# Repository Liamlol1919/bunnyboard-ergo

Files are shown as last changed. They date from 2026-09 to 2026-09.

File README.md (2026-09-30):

# bunnyboard
this is a custom stenography keyboard i built with [hackclub's onboard grant](https://onboard.hackclub.com)!

## ergo variant (working copy)
This tree contains a transformed variant of the original bunnyboard: the same
electrical design (pads, nets, matrix, diodes, Pico pinout are bit-identical),
only the (x, y, rot) values of the 28 switches, 28 diodes and the Pico are
changed. Generated by `tools/ergo_transform.py`, routed by `tools/route.sh`.

### pitch: 19 mm grid, not measured fingertip distance
Two candidates were compared (`tools/vergleich_pitch.py`):

| | Pinky-Index | Ring-Middle cap gap |
|---|---|---|
| V1 fingertip (Wacom dx) | 56.0 mm | **0.5 mm** |
| V2 19 mm switch grid | 57.0 mm | **4.0 mm** |

V1 is rejected: a 0.5 mm gap between the Ring and Middle caps means a
mis-hit presses two keys at once. The measured fingertip spacing is narrower
than the switch grid because the hand rests spread out; the grid has to
follow the switch pitch (Choc = 19 mm), not the fingertips. Stagger (dy) is
taken from the measurement - that is the actual ergonomic effect.

### middle gap: 120 mm
The two middle fingers sit 120 mm apart (measured: 84-92 mm). The extra width
pays for the Pico: it is 23.1 mm wide and sits between the asterisk columns,
which additionally need 2 x 9.125 mm for their diode offsets plus clearance
-> 42.1 mm between the asterisk caps. At 96 mm the asterisks were only 28 mm
apart and the Pico overlapped S6/S17.

### thumb rotation: 3 degrees
The 3 thumb keys per hand are rotated so they face the thumb instead of
standing axis-parallel. Left hand +3, right hand -3.
NOTE: the Choc footprint is NOT mirror-symmetric - all six thumb switches
have the same pad axis (22.78 deg) in the source board. The sign therefore
cannot be derived from "mirror the left hand"; it is set per hand and must
be verified visually on the render. The angle is limited by the caps, not by taste:
a Choc-1u cap is 17.5 x 16.5 mm (the 15 mm used in the first calculation was
too optimistic), and rotating a cap by a widens its bounding box to
17.5*(cos a + sin a). S23 and S24 are 19.36 mm apart:

| angle | cap bbox | gap S23-S24 |
|---|---|---|
| 0 | 17.50 mm | +1.86 mm |
| **3 (chosen)** | 18.39 mm | **+0.97 mm** |
| 6 | 19.23 mm | +0.13 mm |
| 12 | 20.76 mm | -1.40 mm overlap |

DRC does not catch cap collisions - it only checks copper. At 12 degrees the
two caps physically touch, which only shows up during assembly.

### chamfer: outer corners only
The T-outline transition from the bank to the tongue is a concave corner.
A chamfer there cuts away material the corner needs. Fase is applied only to
the convex corners: the 4 bank corners and the 2 tongue ends.

### outline
`Edge.Cuts` is rebuilt as a T shape from the actual key extents, not from the
raw bounding box of the source board. Margin is 4 mm from the keycap edge
(previously 12.5 mm as in bunnys original): a board that lies flat does not
need more, and JLCPCB only requires 0.2 mm copper-to-edge - the smallest
actual copper-to-edge distance here is 1.62 mm.

The copper logo (`G***`) was removed: it is decoration and cost board area.

| | before | after |
|---|---|---|
| Board | 253.6 x 114.2 mm | **236.6 x 97.2 mm** |
| Margin (cap edge to board edge) | 10.5-12.5 mm | 4.0 mm |
| Copper to edge (min) | - | 1.62 mm |

## specs and other stuff
- powered by a Raspberry Pi Pico
- runs QMK firmware
- uses Kailh choc v1 switches

## keyboard layout
the keyboard layout is almost identical to "The Uni" stenokeyboard, except for the top-left key (which is a "#" instead of an "S").
```
.------------------------------------------------.
| # | T | P | H | * |    | * | F | P | L | T | D |
| S | K | W | R | * |    | * | R | B | G | S | Z |
'-------| # | A | O |    | E | U | # |-----------'
        '----------------------------'
```
## how to get this keyboard
1. get the pcb and solder the components
   - PCB gerber located at "/keyboard/production/gerber.zip
   - components needed:
     - 28 kailh v1 choc switches + keycaps (i got mine for $32 USD at chosfox!)
     - raspberry pi pico + header pins
     - 28 1N4148 Diodes (you can choose to have them soldered on if you're using JLCPCB)
2. install the QMK firmware (read [here](https://docs.qmk.fm/newbs_flashing) for more info)
3. install/setup plover (see a tutorial [here](https://docs.stenokeyboards.com/guides/))
   - select "Gemini PR" as your keyboard
   - set output to "Enabled"
4. profit

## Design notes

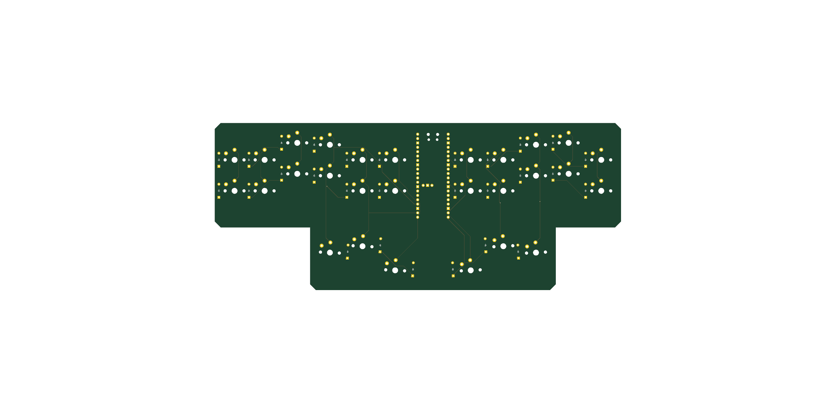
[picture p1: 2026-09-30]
docs/board_bottom.png

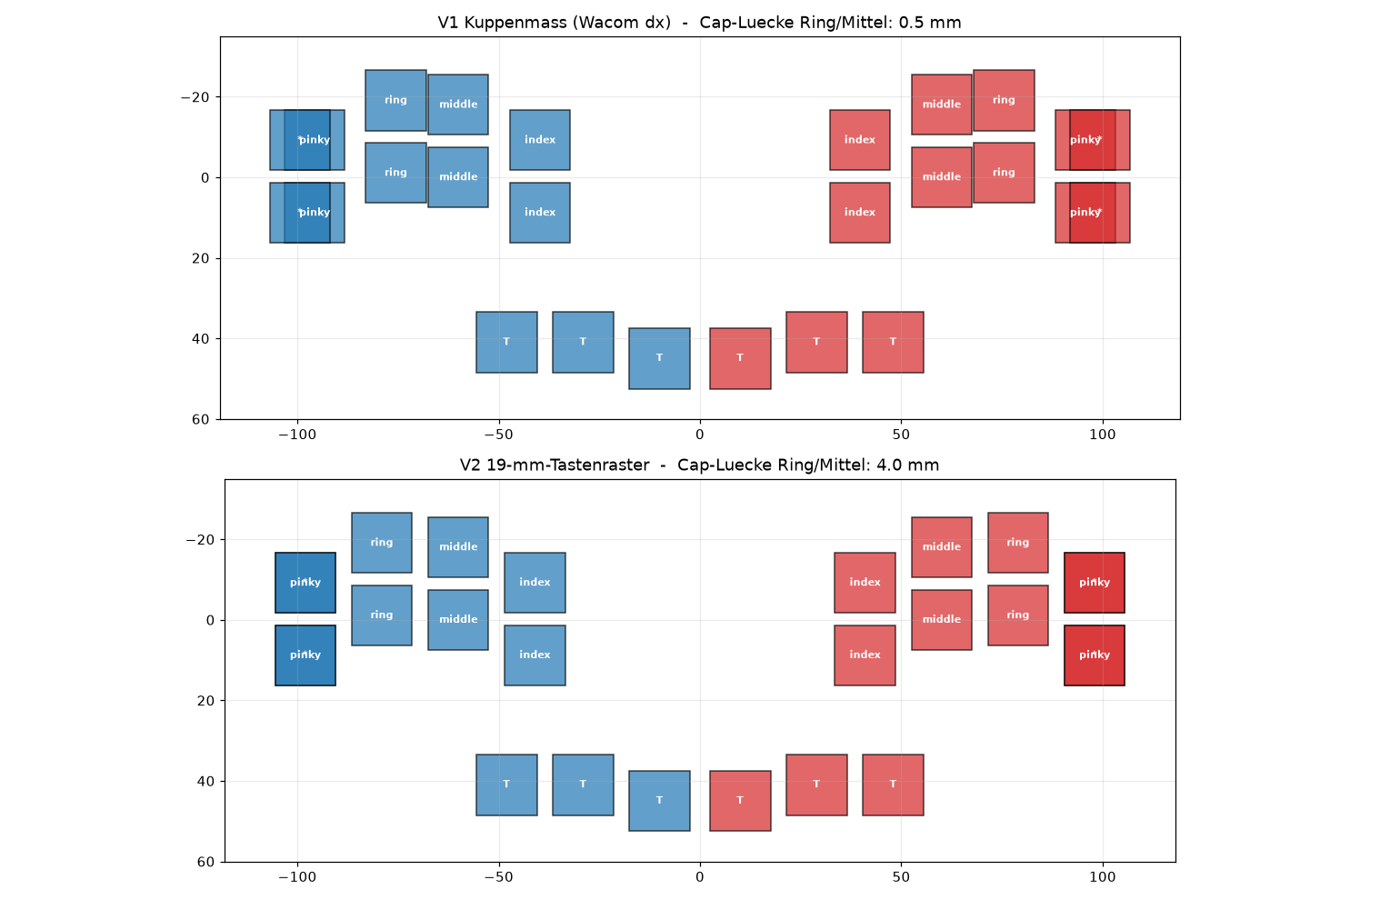
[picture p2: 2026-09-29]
vergleich_pitch.png

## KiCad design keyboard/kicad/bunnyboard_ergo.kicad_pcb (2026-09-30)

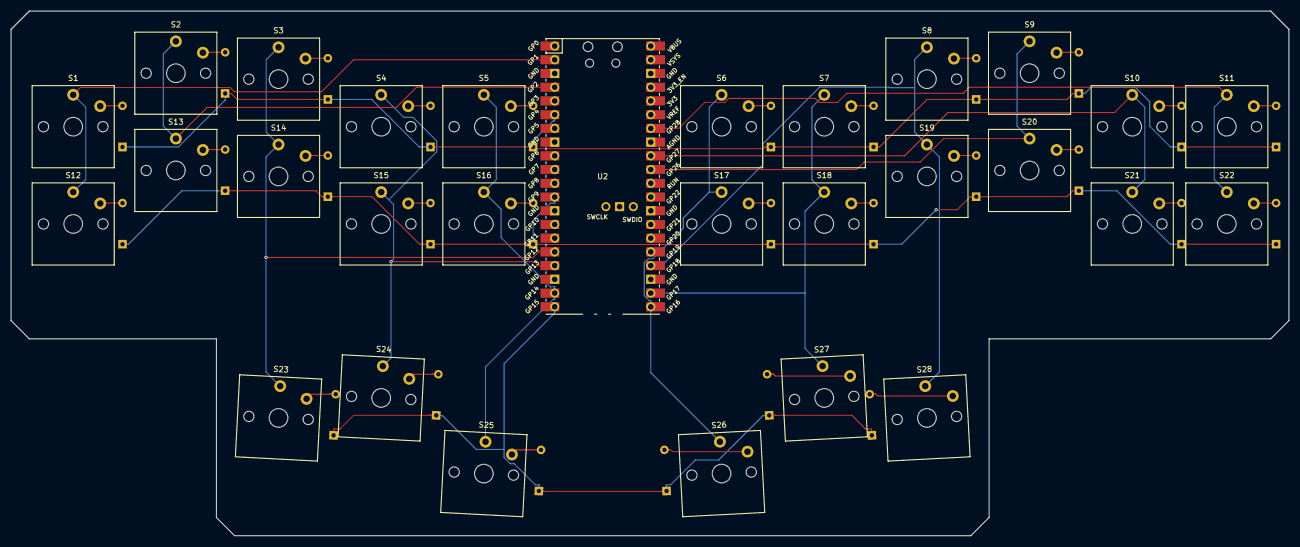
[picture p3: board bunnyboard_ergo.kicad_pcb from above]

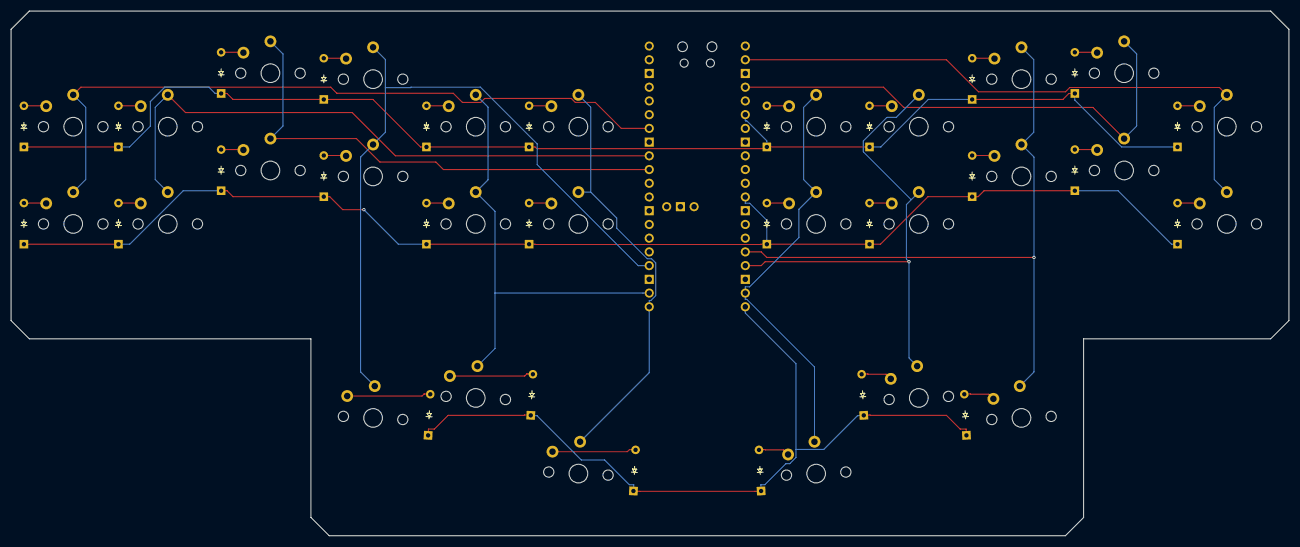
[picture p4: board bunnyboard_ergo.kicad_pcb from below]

Board: 2 copper layers, 236.5 x 97.1 mm, 57 parts (28 on the bottom side), 42 nets.

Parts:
D1, D2, D3, D4, D5, D6, D7, D8, D9, D10, D11, D12, D13, D14, D15, D16, D17, D18, D19, D20, D21, D22, D23, D24, D25, D26, D27, D28: D; Diode_DO-35
S1, S2, S3, S4, S5, S6, S7, S8, S9, S10, S11, S12, S13, S14, S15, S16, S17, S18, S19, S20, S21, S22, S23, S24, S25, S26, S27, S28: Keyswitch; Choc_V1_1.00u
U2: Pico; RPi_PicoW_SMD_TH

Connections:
Column 0: S1.1, S12.1, U2.2 (GPIO1)
Column 1: S2.1, S13.1, U2.4 (GPIO2)
Column 2: S3.1, S14.1, S23.1, U2.16 (GPIO12)
Column 3: S4.1, S15.1, S24.1, U2.17 (GPIO13)
Column 4: S5.1, S16.1, S25.1, U2.19 (GPIO14)
Column 5: S6.1, S17.1, S26.1, U2.21 (GPIO16)
Column 6: S7.1, S18.1, S27.1, U2.22 (GPIO17)
Column 7: S8.1, S19.1, S28.1, U2.24 (GPIO18)
Column 8: S9.1, S20.1, U2.31 (GPIO26_ADC0)
Column 9: S10.1, S21.1, U2.32 (GPIO27_ADC1)
Column 10: S11.1, S22.1, U2.34 (GPIO28_ADC2)
unnamed: D1.2 (A), S1.2
unnamed: D2.2 (A), S2.2
unnamed: D3.2 (A), S3.2
unnamed: D4.2 (A), S4.2
unnamed: D5.2 (A), S5.2
unnamed: D6.2 (A), S6.2
unnamed: D7.2 (A), S7.2
unnamed: D8.2 (A), S8.2
unnamed: D9.2 (A), S9.2
unnamed: D10.2 (A), S10.2
unnamed: D11.2 (A), S11.2
unnamed: D12.2 (A), S12.2
unnamed: D13.2 (A), S13.2
unnamed: D14.2 (A), S14.2
unnamed: D15.2 (A), S15.2
unnamed: D16.2 (A), S16.2
unnamed: D17.2 (A), S17.2
unnamed: D18.2 (A), S18.2
unnamed: D19.2 (A), S19.2
unnamed: D20.2 (A), S20.2
unnamed: D21.2 (A), S21.2
unnamed: D22.2 (A), S22.2
unnamed: D23.2 (A), S23.2
unnamed: D24.2 (A), S24.2
unnamed: D25.2 (A), S25.2
unnamed: D26.2 (A), S26.2
unnamed: D27.2 (A), S27.2
unnamed: D28.2 (A), S28.2
Row 0: D1.1 (K), D2.1 (K), D3.1 (K), D4.1 (K), D5.1 (K), D6.1 (K), D7.1 (K), D8.1 (K), D9.1 (K), D10.1 (K), D11.1 (K), U2.6 (GPIO4)
Row 1: D12.1 (K), D13.1 (K), D14.1 (K), D15.1 (K), D16.1 (K), D17.1 (K), D18.1 (K), D19.1 (K), D20.1 (K), D21.1 (K), D22.1 (K), U2.12 (GPIO9)
Row 2: D23.1 (K), D24.1 (K), D25.1 (K), D26.1 (K), D27.1 (K), D28.1 (K), U2.20 (GPIO15)

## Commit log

2026-09-29 ergo: T-Outline an Tasten, Pico in Mittelluecke, Routing 0 DRC
    - Edge.Cuts aus Tastenausdehnung neu gebaut (253.6 x 103.9 statt 234x171
    mit 65% Leerflaeche im Sueden)
    - GAP 96 -> 120: Pico (23.1 breit) braucht 2x9.125 Dioden-Offset + Luft
    zwischen den Asterisk-Kappen
    - Pico-Zentrum symmetrisch: rechts mid_r+DX_INDEX-19 (vorher fehlte -19,
    Pico lag auf S6/S17)
    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
    [bunnyboard_ergo.kicad_pcb]
2026-09-29 ergo: Pitch V2 dokumentiert, Logo mitverschoben, neu geroutet
    - README: Abschnitt 'ergo variant' mit Pitch-Entscheidung (V1 Kuppenmass
    verwworfen: 0.5 mm Cap-Luecke Ring/Mittel; V2 19-mm-Raster: 4.0 mm),
    GAP-120-Begruendung und Outline-Herkunft
    - vergleich_pitch.py auf GAP 120 nachgezogen (war 96)
    - Kupfer-Logo G*** mitverschoben: lag nach dem Transform ausserhalb von
    Edge.Cuts (Quelle 140.69/119.17 -> Ziel frei ueber der Bank, 104/-30)
    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
    [bunnyboard_ergo.kicad_pcb]
2026-09-29 ergo: Daumen-Cluster korrigiert (S23/S25 vertauscht), Produktionsdaten, Viewer
    Fehler gefunden beim Vergleich Quell- vs Zielboard:
    - Daumen-y war S23/S28=41.0 und S25/S26=44.7 - vertauscht. STAGGER.md:
    Taste1 (A/E, Ruhepunkt) +45, Taste2 (O/U, 19 innen) +41, Extra X1/X2 +55.
    Jetzt S23/S28=44.7, S24/S27=41.0, S25/S26=55.0.
    - keyboard/production/gerber.zip war das ORIGINAL vom 11.03.2024, nicht das
    Ergo-Board. Neu: keyboard/production/gerber_ergo.zip (26 Dateien) mit
    frischen Gerbern, Drill und positions.csv.
    docs/ergebnis.html: selbsttragender Viewer (Bilder inline + massstaeblicher
    SVG-Routingplan + Verifikationstabelle).
    Verifikation: 252 Tracks, 0 DRC, 0 unconnected, min Daumen-K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
    [bunnyboard_ergo-B_Courtyard.gbr, bunnyboard_ergo-B_Cu.gbl, bunnyboard_ergo-B_Fab.gbr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]
2026-09-29 ergo: Board kompakter - Logo raus, Rand 10.5 -> 4.0 mm
    - Kupfer-Logo G*** entfernt (Dekoration, kostete Flaeche). Wichtig: Remove()
    vor dem Track-Loeschen, sonst toter SWIG-Handle (Segfault in der
    Footprint-Iteration).
    - Rand vom Kappenrand zur Boardkante 10.5-12.5 -> 4.0 mm rundum. Neuer
    Umriss beruecksichtigt zusaetzlich den Pico, der 7 mm ueber die Bank ragt
    (haette sonst ausserhalb von Edge.Cuts gelegen).
    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
    [bunnyboard_ergo-B_Courtyard.gbr, bunnyboard_ergo-B_Cu.gbl, bunnyboard_ergo-B_Fab.gbr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]
2026-09-30 ergo: Daumen 3 Grad gedreht, Innen-Fase entfernt
    Umriss:
    - Chamfer nur noch an konvexen Ecken (4 Bank-Ecken, 2 Zungen-Enden). Der
    Bank->Zunge-Uebergang ist konkav - eine Fase schnitt dort Material weg,
    das die Ecke traegt. 16 -> 14 Punkte.
    Daumen:
    - Die 6 Daumentasten sind um 3 Grad zum Daumen gedreht (links negativ,
    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
    [bunnyboard_ergo-B_Courtyard.gbr, bunnyboard_ergo-B_Cu.gbl, bunnyboard_ergo-B_Fab.gbr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]
2026-09-30 ergo: Daumen rechts korrigiert (links +3, rechts -3), Dioden im Cluster entzerrt
    - Drehrichtung rechts umgekehrt: vorher beide -3, jetzt links +3 / rechts -3.
    Das Choc-Footprint ist nicht spiegelsymmetrisch (alle 6 Daumentasten haben
    im Quellboard dieselbe Pad-Achse 22.78 Grad), die Spiegelung ergibt sich
    daher nicht aus dem Vorzeichen allein.
    - Dioden-Offsets im Daumencluster explizit je Taste (THUMB_DIODE_OX).
    Vorher kollidierten D27 (+10 -> x=51.2) und D28 (-8 -> x=52.2) mit 1 mm
    Abstand (courtyards_overlap). Jetzt zeigen alle zur Cluster-Mitte:
    S23/S28 8.0, S24/S25/S26/S27 10.0, jeweils mit Seitenvorzeichen.
    - Verifikation: 283 Tracks, 0 DRC, 0 unconnected, 0 ausserhalb Edge.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
    [bunnyboard_ergo-B_Courtyard.gbr, bunnyboard_ergo-B_Cu.gbl, bunnyboard_ergo-B_Fab.gbr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]
2026-09-30 ergo: Viewer-Bug behoben (SVG ohne Groesse), Daumen-Vorzeichen getauscht
    Viewer:
    - Die Plaene hatten viewBox-Werte in Pixeln, aber width/height fehlten, und
    der Zoom erbte die volle Boardhoehe (1626x2301 statt ~600x600). Deshalb war
    nichts zu sehen. Jetzt explizite width/height + eigener Crop fuer den Zoom.
    - docs/ergebnis.html zeigt beide Vorzeichen-Varianten nebeneinander:
    A links +3 / rechts -3, B links -3 / rechts +3.
    - Vorzeichen getauscht: links jetzt -3, rechts +3.
    - Pipeline neu gelaufen: 290 Tracks, 0 DRC, 0 unconnected.
    Umschalten ist eine Zeile in tools/ergo_transform.py (THUMB_ROT-Zeichen
    in den sechs out[...]-Zeilen bei target_positions()).
    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
    [bunnyboard_ergo-B_Courtyard.gbr, bunnyboard_ergo-B_Cu.gbl, bunnyboard_ergo-B_Fab.gbr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]
2026-09-30 ergo: Daumen-Vorzeichen auf die am PCB bestaetigte Variante A zurueck
    - Vorzeichen wieder links +3 / rechts -3. Der Tausch auf B in 2685737 war
    falsch (Nutzer hat A am PCB bestaetigt).
    - Nur S23-S28 werden gedreht; S1-S22 und der Pico bleiben bei rot = 0.
    - Veralteten Kommentar korrigiert: der Winkel kommt nicht aus der gemessenen
    Daumenachse (125-134 Grad), sondern ist durch die Kappenbreite begrenzt.
    - Viewer: beide Daumen-Cluster einzeln im Zoom statt einer Vorzeichen-
    Gegenueberstellung, da die Richtung jetzt feststeht.
    - 283 Tracks, 0 DRC, 0 unconnected.
    [bunnyboard_ergo-B_Courtyard.gbr, bunnyboard_ergo-B_Cu.gbl, bunnyboard_ergo-B_Fab.gbr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]
2026-09-30 ergo: Daumen links/rechts entgegengesetzt gedreht, Plan in Render-Orientierung
    - Links -3 Grad, rechts +3 Grad. Vorher drehten beide Seiten gleichsinnig
    (Render-Achse beide -19.78 bzw. beide -25.78), die Kappen kippten also
    nicht gespiegelt zueinander.
    - Nachweis ueber die Pad-Achse im Render-Koordinatensystem (y nach oben):
    links -25.78 Grad, rechts -19.78 Grad -> gespiegelt.
    - Plan (docs/ergebnis.html) wird jetzt in derselben Orientierung wie der
    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
    [bunnyboard_ergo-B_Courtyard.gbr, bunnyboard_ergo-B_Cu.gbl, bunnyboard_ergo-B_Fab.gbr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]
2026-09-30 docs: Plan-Orientierung korrigiert, Daumen-Zoom entfernt
    - Der Gesamtplan war vertikal gespiegelt: die Zunge stand oben statt unten.
    Ursache war ein falsch zusammengesetztes scale(1,-1)+translate. Jetzt wird
    y direkt als (Y1-y)*S abgebildet, ohne Transform: Bank oben (breit),
    Zunge unten (schmal) wie im 3D-Render.
    - Daumen-Zoom entfernt, es bleibt nur der Gesamtplan.
    - Das PCB selbst ist unveraendert (Render byte-identisch).
2026-09-30 docs: Plan y-Achse korrigiert - KiCad bildet +y nach unten ab
    - Falsche Annahme korrigiert: der 3D-Render bildet +y nach UNTEN ab (wie die
    Datei), nicht nach oben. Meine letzte Aenderung (y gespiegelt, Winkel
    negiert) hat den Plan deshalb umgedreht: Zunge stand oben.
    - Jetzt wieder py(y)=(y-Y0)*S und Winkel unveraendert.
    - Verifiziert am gelieferten HTML: Zunge y 306..474 (unten), Daumen plan-y
    421, Bank oben - deckt sich mit board_top.png (Bank oben 1158 px breit,
    Zunge unten 700 px).
    - PCB/Render unveraendert.
2026-09-30 ergo: Daumenwinkel auf 6 Grad (nach innen)
    - THUMB_ROT 3 -> 6. Richtung unveraendert (links -6, rechts +6).
    - Nur S23-S28 gedreht; S1-S22 und Pico bleiben bei 0. PCB-Geometrie
    (Umriss, Pico, Finger) unangetastet.
    - Kappenluecke S23-S24 sinkt von 0.94 auf 0.13 mm (Kappen-BBox 19.23 mm
    bei 19.36 mm Mittenabstand). Ab 8 Grad ueberlappen die Kappen.
    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
    [bunnyboard_ergo-B_Courtyard.gbr, bunnyboard_ergo-B_Cu.gbl, bunnyboard_ergo-B_Fab.gbr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]
2026-09-30 ergo: Daumen 9 Grad in V-Form (links +9, rechts -9)
    - Richtung gedreht: links +THUMB_ROT, rechts -THUMB_ROT. Die Kappen kippen
    damit zur Mitte nach oben, es entsteht ein V zwischen den Daumen.
    Vorzeichen ueber die Oberkanten-Normale im SVG-Koordinatensystem
    hergeleitet: n = (sin a, -cos a); links muss nach rechts kippen (a>0),
    rechts nach links (a<0). Gegenprobe Pad-Achse: links 13.78, rechts 31.78.
    - Winkel 9 Grad (nicht 6): 3 Grad + 6 Grad weiter nach innen.
    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
    [bunnyboard_ergo-B_Courtyard.gbr, bunnyboard_ergo-B_Cu.gbl, bunnyboard_ergo-B_Fab.gbr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]
2026-09-30 ergo: Daumenwinkel zurueck auf 3 Grad, V-Form beibehalten
    - THUMB_ROT 9 -> 3. Richtung unveraendert: links +3 (Kappe kippt nach
    rechtsoben), rechts -3 (nach linksoben) -> V zwischen den Daumen.
    - Dioden-Offsets bleiben bei +-10.0 (zur Cluster-Mitte).
    - Nur S23-S28 gedreht; S1-S22 und Pico bei 0. Umriss/Pico unveraendert,
    Board 236.6 x 97.2 mm.
    - 282 Tracks, 0 DRC, 0 unconnected.
    [bunnyboard_ergo-B_Courtyard.gbr, bunnyboard_ergo-B_Cu.gbl, bunnyboard_ergo-B_Fab.gbr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]
2026-09-30 ergo: Daumenrichtung umgedreht, 3 Grad (links -3, rechts +3)
    - Vorzeichen getauscht: links -THUMB_ROT, rechts +THUMB_ROT. Die
    Kappen-Oberkante kippt jetzt von der Mitte nach aussen.
    - Winkel bleibt 3 Grad.
    - Gegenprobe Pad-Achse: links -3 -> 25.78, rechts +3 -> 19.78 (gespiegelt).
    - Dioden-Offsets +-10.0 unveraendert.
    - 290 Tracks, 0 DRC, 0 unconnected.
    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
    [bunnyboard_ergo-B_Courtyard.gbr, bunnyboard_ergo-B_Cu.gbl, bunnyboard_ergo-B_Fab.gbr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]
